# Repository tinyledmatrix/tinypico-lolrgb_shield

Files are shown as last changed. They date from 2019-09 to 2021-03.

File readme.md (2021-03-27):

[Buy a LOL RGB Shield](https://unexpectedmaker.com/shop/tinypico-shield-lolrgb)

## 5*14 RGB-LED shield for tinypico esp-32 board
# General
* for use with tinypico esp32 board
	* https://www.tinypico.com/
	* https://github.com/tinypico 
	* [Buy a TinyPICO](https://unexpectedmaker.com/shop/tinypico-usbc)
	
* Uses 70 WS2812 LEDs in 151 package
* easy to use with fastLED
* @mcauser wrote a  MicroPython library you can find it [here](https://github.com/mcauser/micropython-tinypico-lol-rgb-shield/)
* integrated level-shifter for data signal 3,3V -> 5V
* integrated reset button (optional to use or populate) 
* connection to tinypico: 5V (supply for LEDs), GND, IO4 or IO25, reset (if switch is used)
	* with R1 or R2 user can select to use IO4 or IO25 for the led data line   
# Images 
see also folder /images
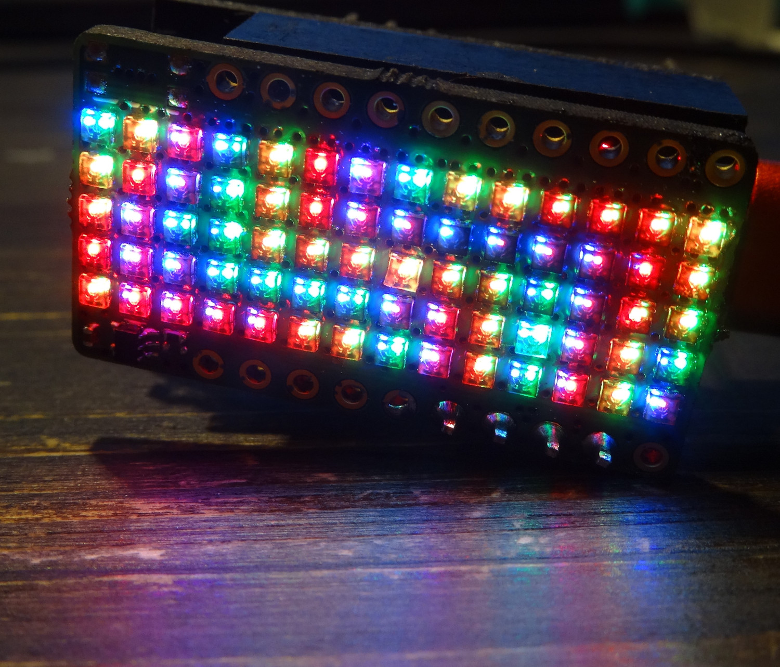
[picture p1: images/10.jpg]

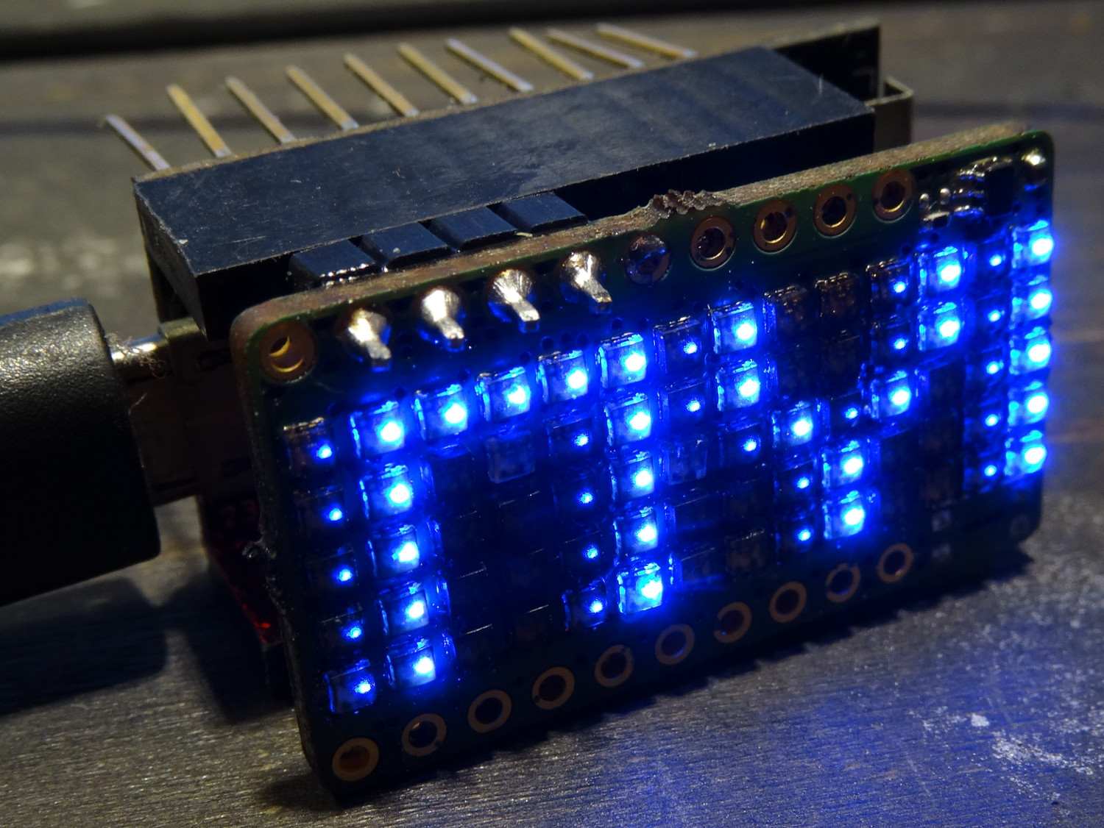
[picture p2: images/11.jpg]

# License 
This is based on the shield template from the orignal repository. So also the licencs is shared.  
These files are released as open source under the CERN license. Please review the license before using these files in your own projects to understand your obligations.

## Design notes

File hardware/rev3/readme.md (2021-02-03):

# Preliminary Files for rev3

Untested! 

Changes:
* Changed Buffer to N-Fet-Buffer 
* Moved datapin to GPIO 14
	* Data-In is no more switchable via resistor 
* Power rail switch to 5V
* rev 3 uses foloowing Pins of tinyPico
	* GND (both are connected - you an use one or both)
	* 3V3 as lower voltage level for level shifter 
	+ 5V as supply voltage for LEDs 
	* GPIO14 data signal for LEDs (needs to be same voltage level as on 3.3V Pin)

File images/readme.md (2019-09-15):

## Some images
Images are in reduced quality. 
If you need more, other or better qualitiy for an articel or similar please contact me. 



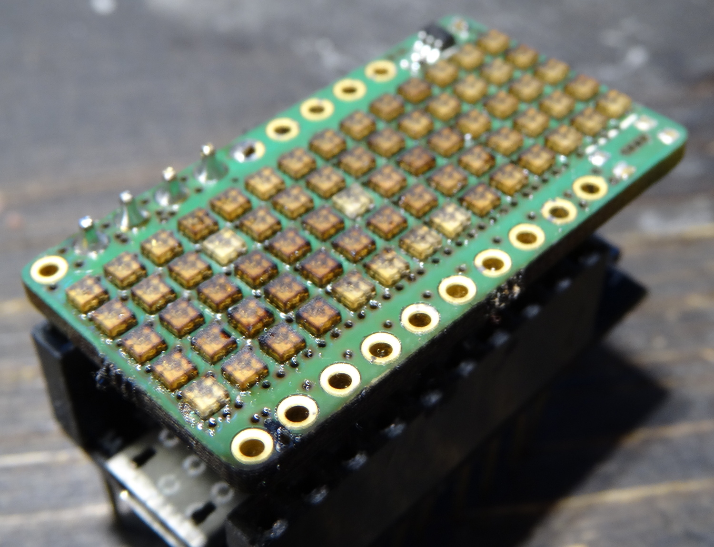
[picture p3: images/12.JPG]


## Licens for all Imges in this folder
CC BY-SA

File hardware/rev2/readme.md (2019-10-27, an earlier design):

# Preliminary Files for rev2

DO NOT USE THIS REVISON. POWERING ALL LEDs FROM THE 3.3V LDO COULD BE PROBLEMATIC!
USE REV3! 

Changes:
* Removed Buffer vor data
* Moved datapin to GPIO 14
	* Data-Oin is nomre switchable via resistor 
* Power rail switch to 3.3V
	* No 5V Power needed anymore
* rev 2 ses foloowing Pins of tinyPico
	* GND (both are connected - youse one or both)
	* 3V3 as supolly voltage for LEDS. (if not used if tinyPico you could also suplly 5V here)
	* GPIO14 data signal for LEDs (neds to be same voltage level as suplly

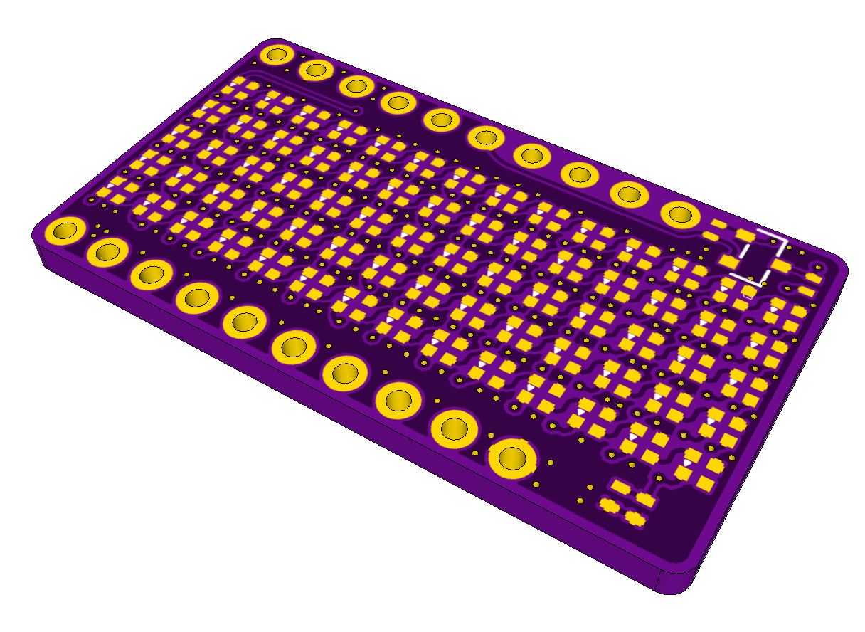
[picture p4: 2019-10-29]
hardware/rev3/renders_PCB/top.JPG

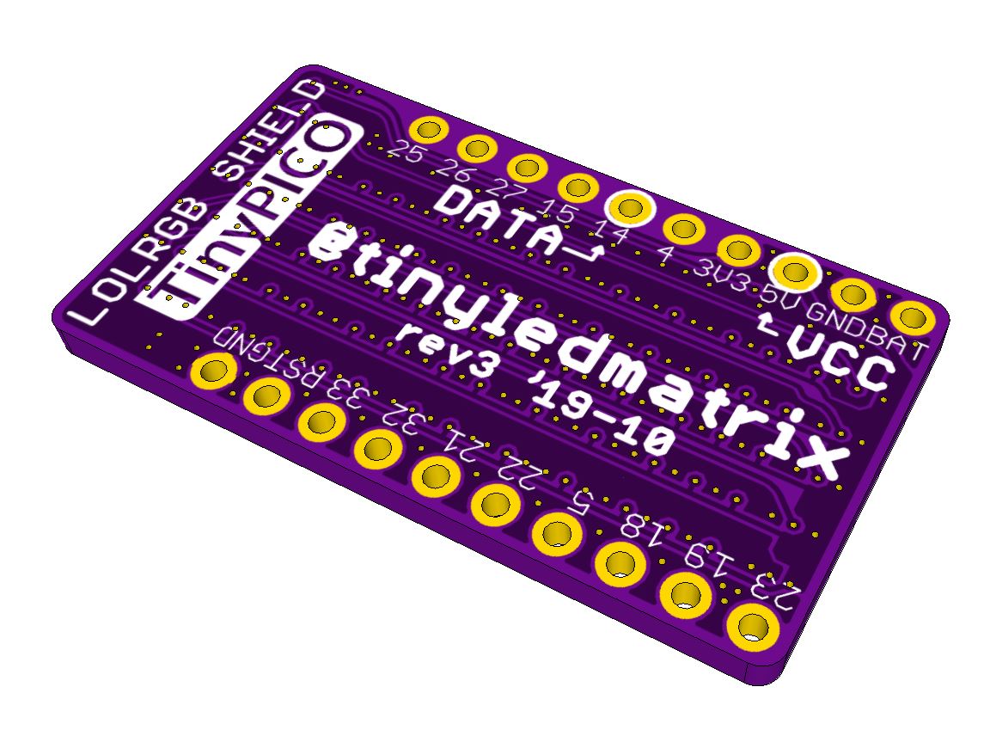
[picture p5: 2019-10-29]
hardware/rev3/renders_PCB/bot.JPG

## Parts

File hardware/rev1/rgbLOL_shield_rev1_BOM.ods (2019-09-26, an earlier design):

Position | Reference | Quantity | Description | Comment | Manufacturer | Package | #Farnell | #Digikey | other sources
1 | LED1-LED70 | 70 | EC15 SK6812 1515 |  | Newstar LED | 1515 (metric) | na | na | Aliexpress, Newstar
2 | R1 | 1 | R0402 0Ohm |  | misc | 0603 | generic | generic
3 | R2 | 1 | R0402 0Ohm | DNP | misc | 0603 | generic | generic
4 | C1 | 1 | C0402 1uF X7R 6.3V |  | misc | 0603 | generic | generic
5 | IC1 | 1 | SN74LV1T34DCKR |  | TI | DCK_R-PDSO-G5 / SC70-5 | 2499915 | 296-37177-1-ND
6 | X1,X2 | 2 | Pinheader 2.54mm 10p | DNP | misc | Pinheader 2.54 | generic | generic

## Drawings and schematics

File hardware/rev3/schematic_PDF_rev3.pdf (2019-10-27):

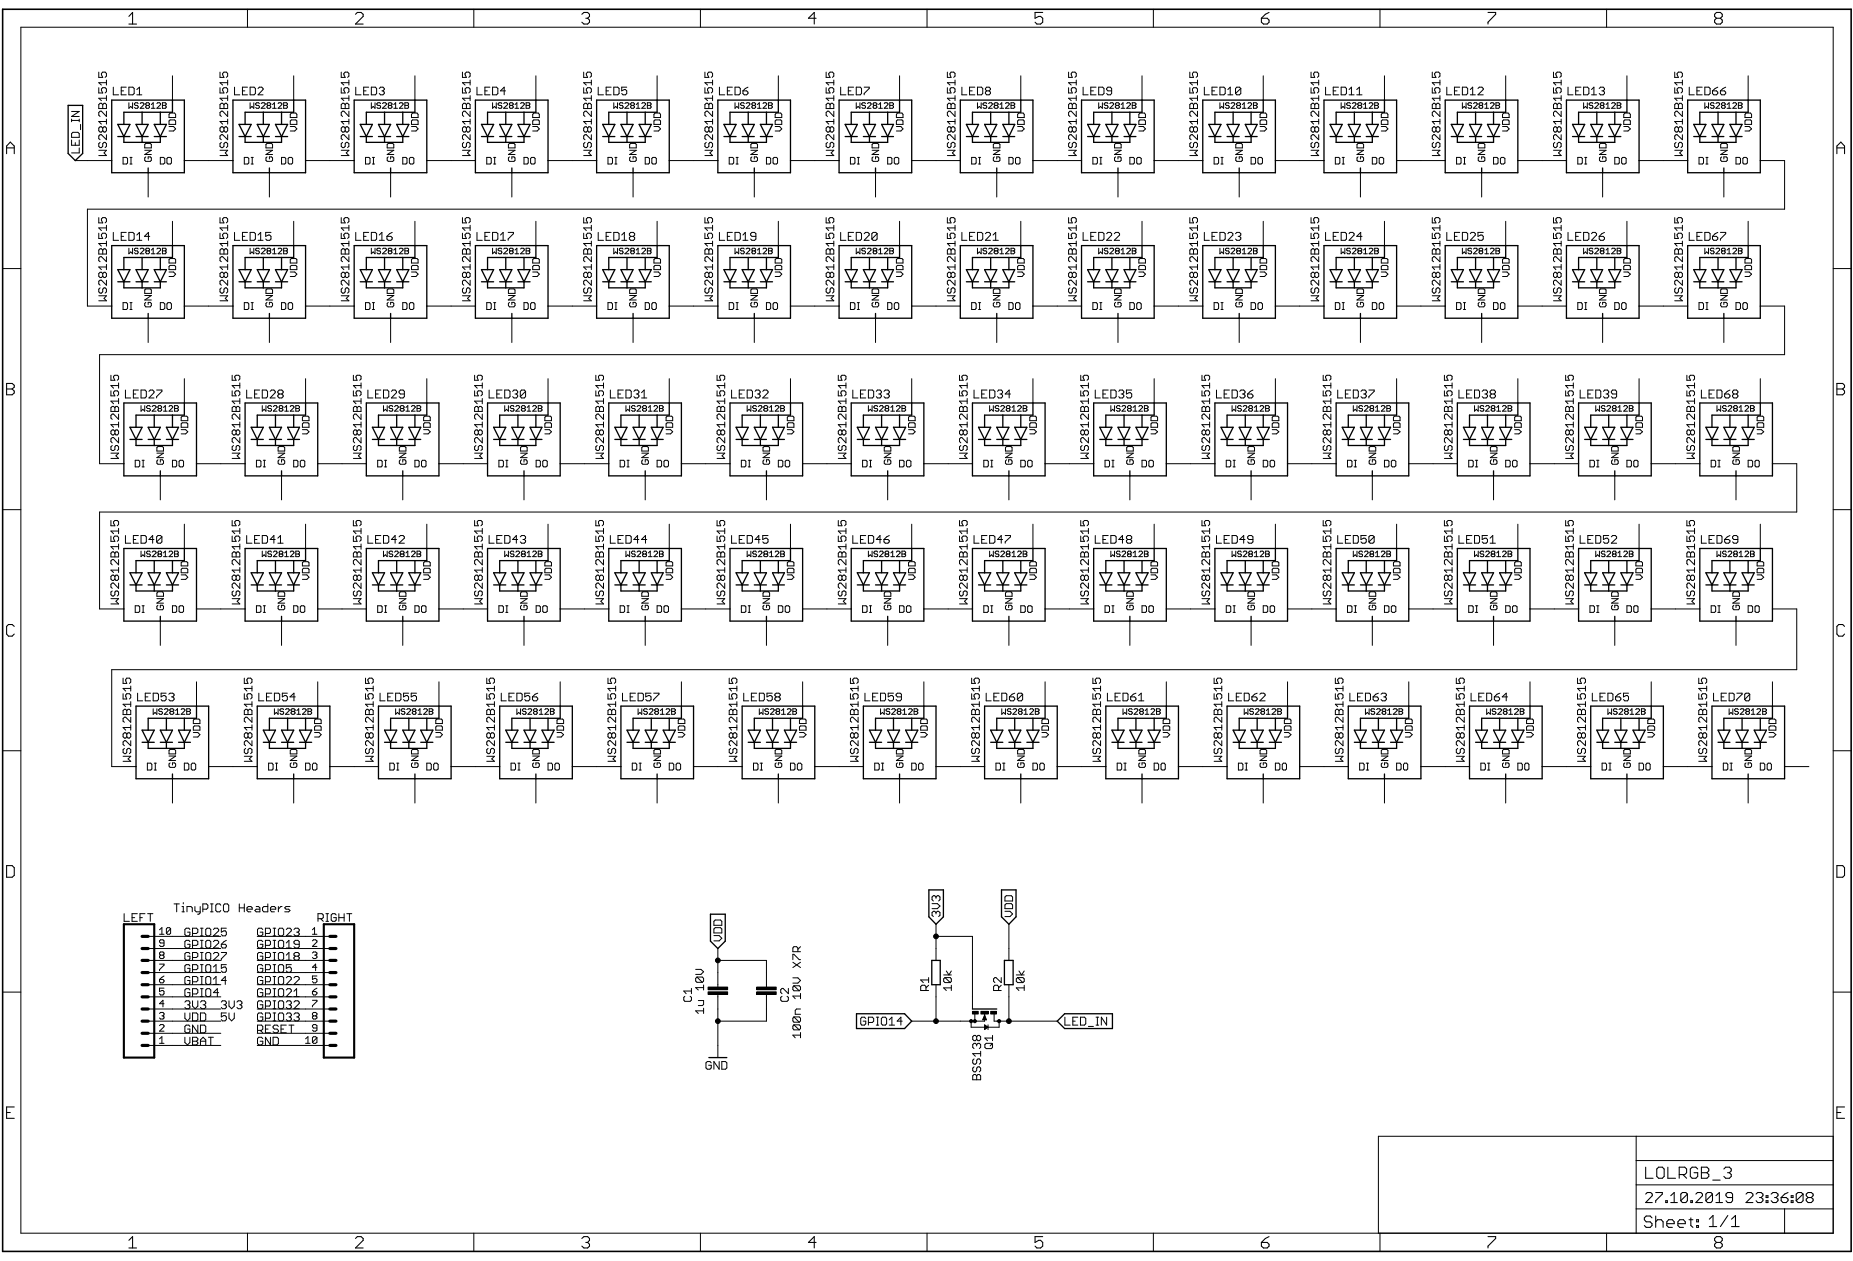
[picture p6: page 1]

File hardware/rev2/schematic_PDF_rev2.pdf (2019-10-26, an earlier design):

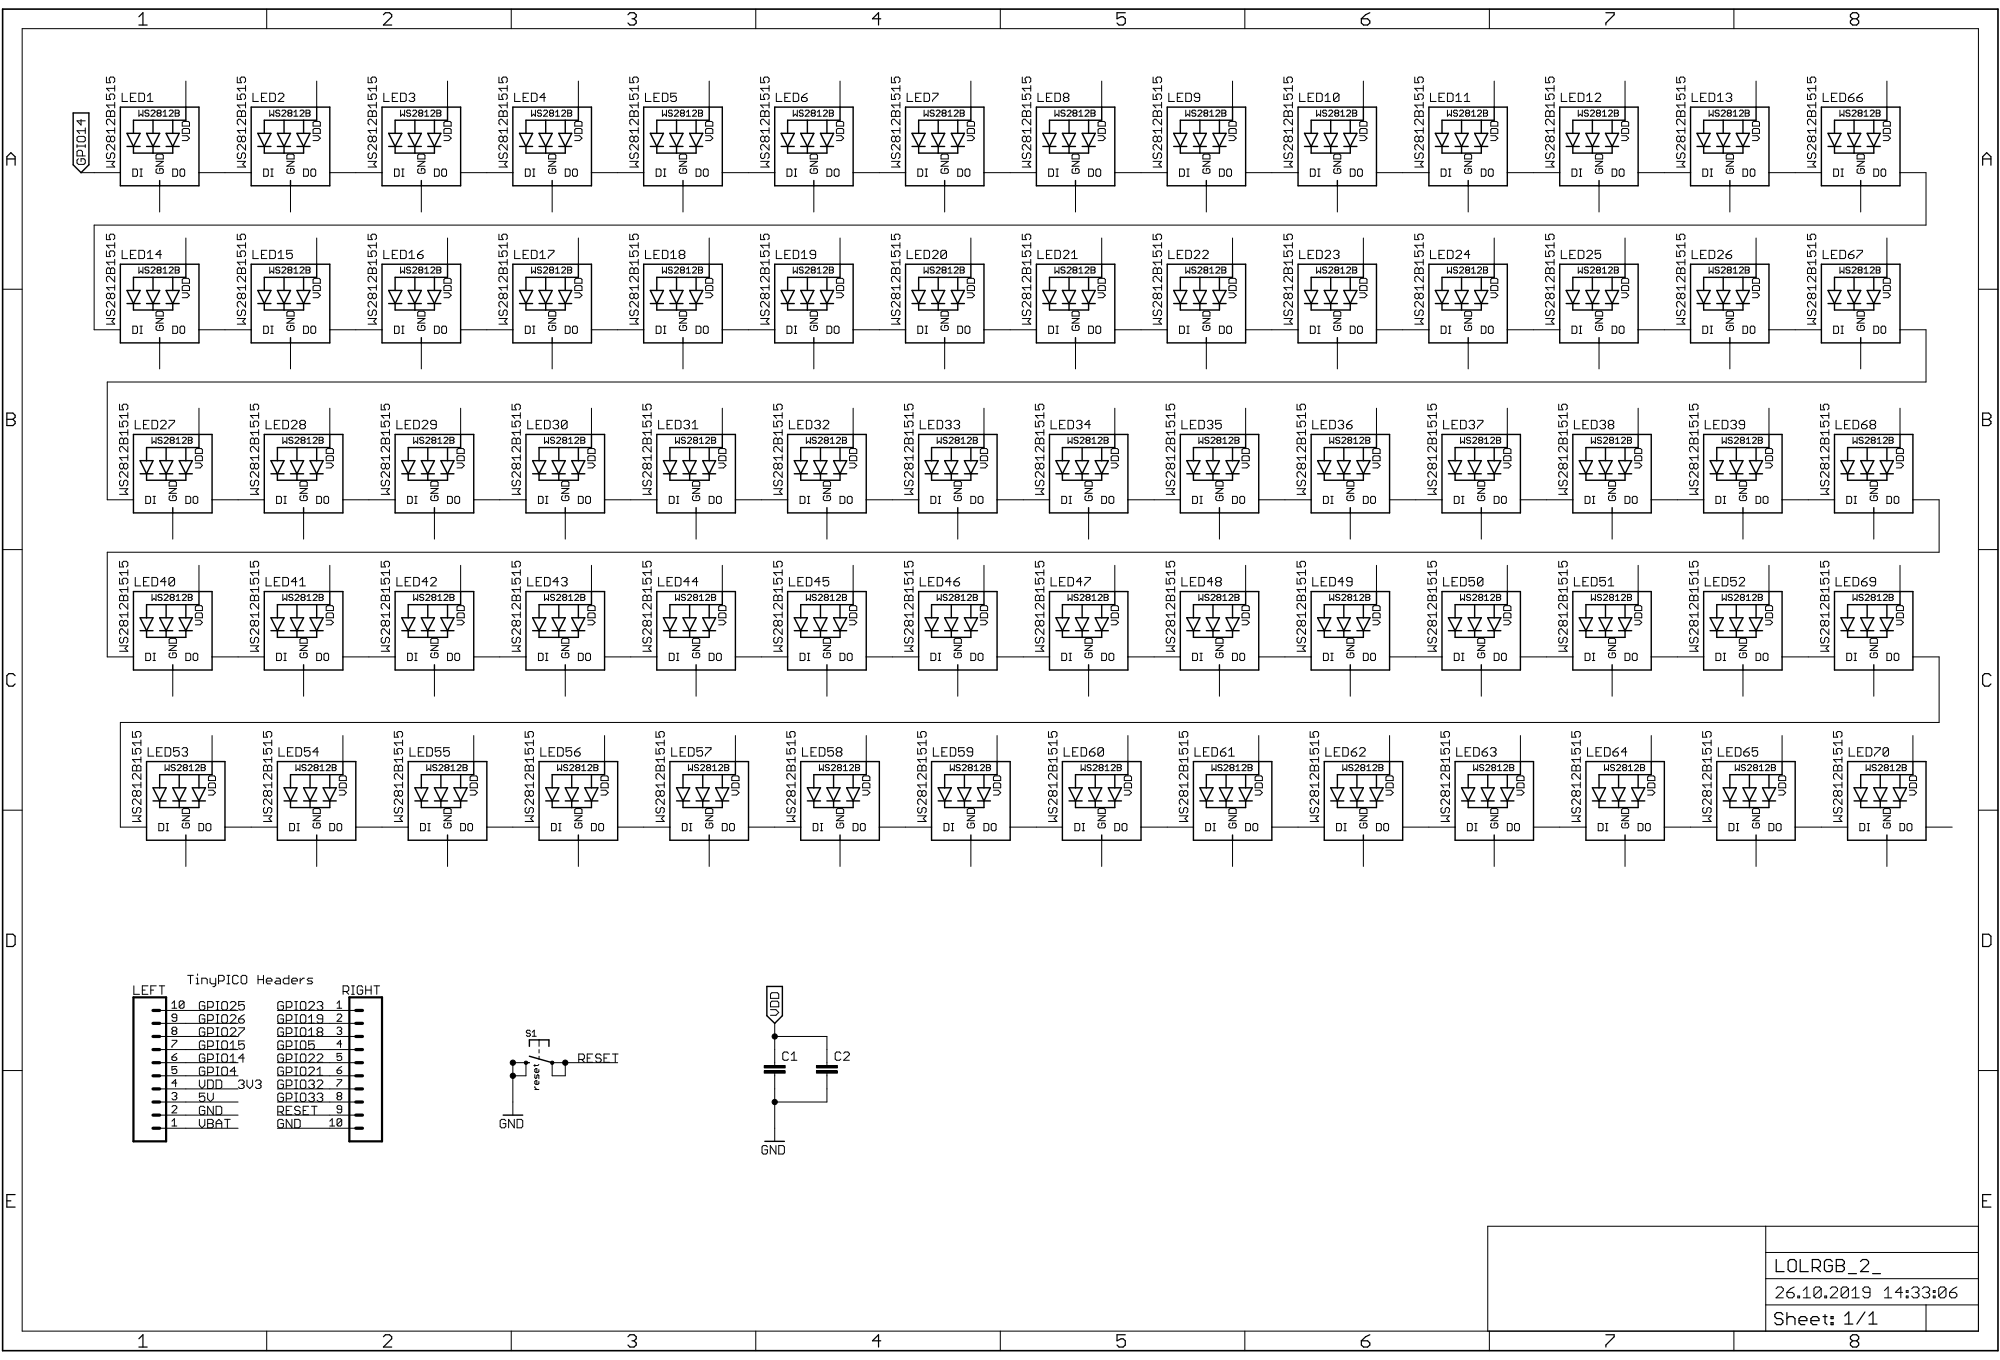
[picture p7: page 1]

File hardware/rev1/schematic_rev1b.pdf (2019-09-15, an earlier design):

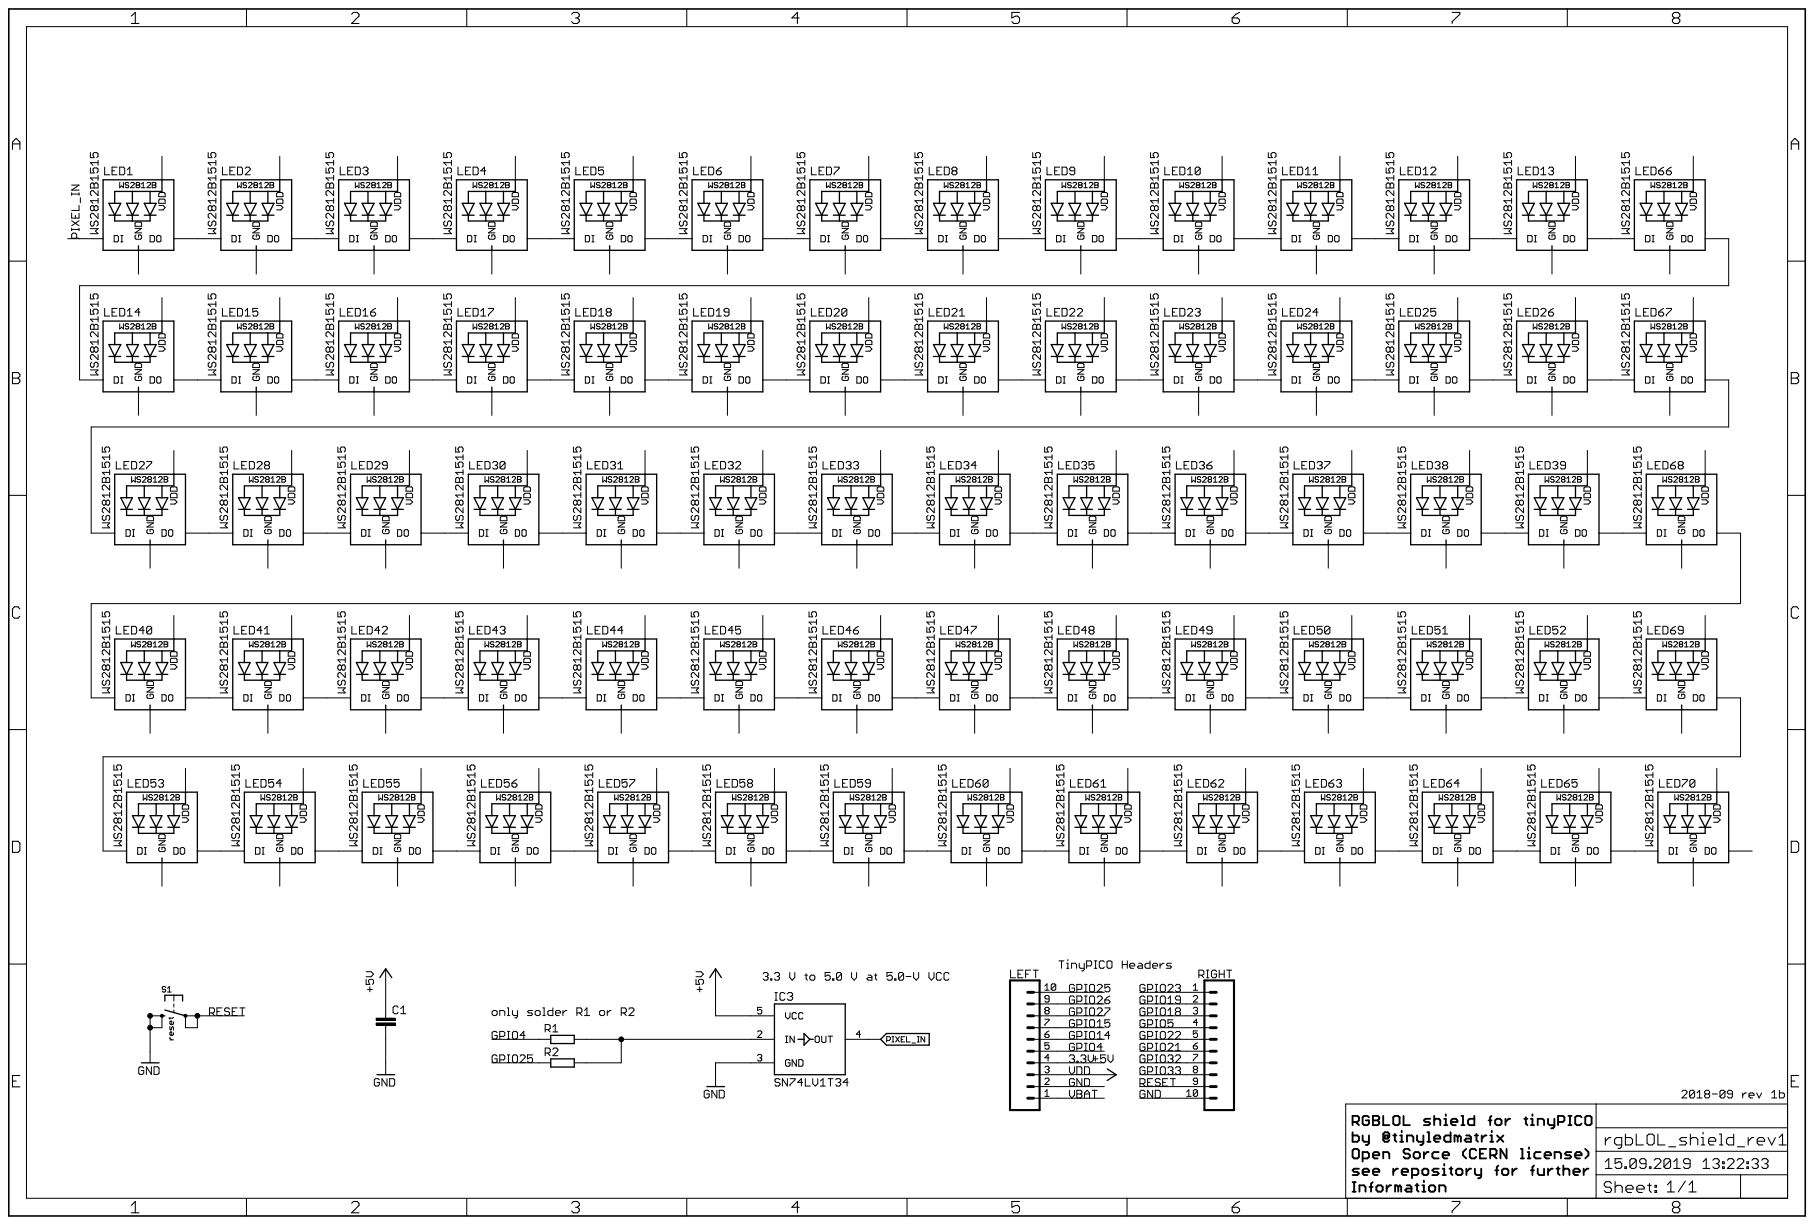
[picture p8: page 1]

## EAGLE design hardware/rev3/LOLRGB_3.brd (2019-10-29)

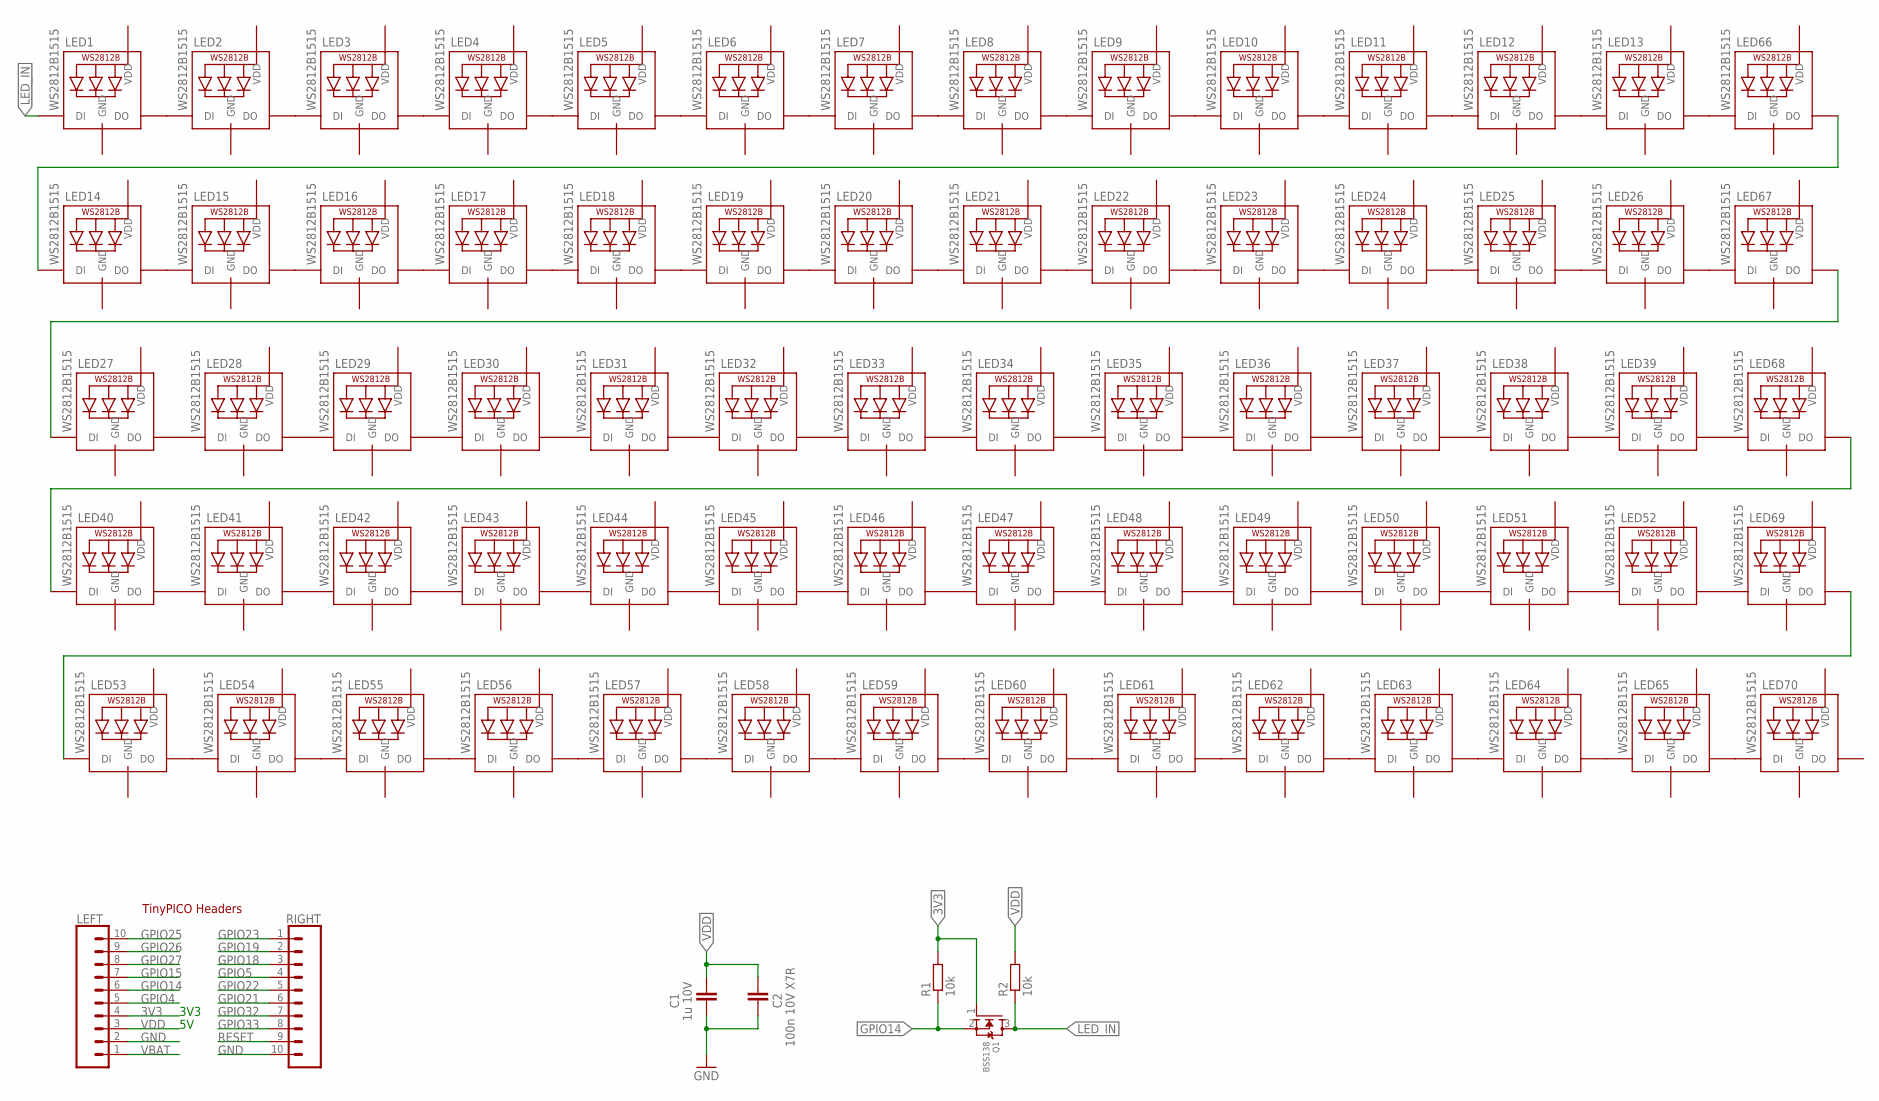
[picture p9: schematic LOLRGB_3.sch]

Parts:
C1: 1u 10V; C0402-VISHAY
C2: 100n 10V X7R; C0402-VISHAY
LED1, LED2, LED3, LED4, LED5, LED6, LED7, LED8, LED9, LED10, LED11, LED12, LED13, LED14, LED15, LED16, LED17, LED18, LED19, LED20, LED21, LED22, LED23, LED24, LED25, LED26, LED27, LED28, LED29, LED30, LED31, LED32, LED33, LED34, LED35, LED36, LED37, LED38, LED39, LED40, LED41, LED42, LED43, LED44, LED45, LED46, LED47, LED48, LED49, LED50, LED51, LED52, LED53, LED54, LED55, LED56, LED57, LED58, LED59, LED60, LED61, LED62, LED63, LED64, LED65, LED66, LED67, LED68, LED69, LED70: WS2812B1515; LED1515
LEFT: TINYPICO_HEADER_10NO_SILK_PTH_FEMALE; 1X10_NO_SILK
Q1: BSS138; SOT23-R
R1, R2: 10k; ADAFRUIT_R0402-VISHAY
RIGHT: TINYPICO_HEADER_10NO_SILK_PTH_FEMALE; 1X10_NO_SILK

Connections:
3V3: LEFT.4, Q1.1 (G), R1.2
GND: C1.2, C2.2, LED1.GND, LED2.GND, LED3.GND, LED4.GND, LED5.GND, LED6.GND, LED7.GND, LED8.GND, LED9.GND, LED10.GND, LED11.GND, LED12.GND, LED13.GND, LED14.GND, LED15.GND, LED16.GND, LED17.GND, LED18.GND, LED19.GND, LED20.GND, LED21.GND, LED22.GND, LED23.GND, LED24.GND, LED25.GND, LED26.GND, LED27.GND, LED28.GND, LED29.GND, LED30.GND, LED31.GND, LED32.GND, LED33.GND, LED34.GND, LED35.GND, LED36.GND, LED37.GND, LED38.GND, LED39.GND, LED40.GND, LED41.GND, LED42.GND, LED43.GND, LED44.GND, LED45.GND, LED46.GND, LED47.GND, LED48.GND, LED49.GND, LED50.GND, LED51.GND, LED52.GND, LED53.GND, LED54.GND, LED55.GND, LED56.GND, LED57.GND, LED58.GND, LED59.GND, LED60.GND, LED61.GND, LED62.GND, LED63.GND, LED64.GND, LED65.GND, LED66.GND, LED67.GND, LED68.GND, LED69.GND, LED70.GND, LEFT.2, RIGHT.10
GPIO4: LEFT.5
GPIO5: RIGHT.4
GPIO14: LEFT.6, Q1.2 (S), R1.1
GPIO15: LEFT.7
GPIO18: RIGHT.3
GPIO19: RIGHT.2
GPIO21: RIGHT.6
GPIO22: RIGHT.5
GPIO23: RIGHT.1
GPIO25: LEFT.10
GPIO26: LEFT.9
GPIO27: LEFT.8
GPIO32: RIGHT.7
GPIO33: RIGHT.8
LED_IN: LED1.DIN (DI), Q1.3 (D), R2.1
unnamed: LED13.DOUT (DO), LED66.DIN (DI)
unnamed: LED1.DOUT (DO), LED2.DIN (DI)
unnamed: LED2.DOUT (DO), LED3.DIN (DI)
unnamed: LED3.DOUT (DO), LED4.DIN (DI)
unnamed: LED4.DOUT (DO), LED5.DIN (DI)
unnamed: LED5.DOUT (DO), LED6.DIN (DI)
unnamed: LED6.DOUT (DO), LED7.DIN (DI)
unnamed: LED7.DOUT (DO), LED8.DIN (DI)
unnamed: LED8.DOUT (DO), LED9.DIN (DI)
unnamed: LED10.DOUT (DO), LED11.DIN (DI)
unnamed: LED9.DOUT (DO), LED10.DIN (DI)
unnamed: LED11.DOUT (DO), LED12.DIN (DI)
unnamed: LED12.DOUT (DO), LED13.DIN (DI)
unnamed: LED14.DOUT (DO), LED15.DIN (DI)
unnamed: LED15.DOUT (DO), LED16.DIN (DI)
unnamed: LED16.DOUT (DO), LED17.DIN (DI)
unnamed: LED17.DOUT (DO), LED18.DIN (DI)
unnamed: LED18.DOUT (DO), LED19.DIN (DI)
unnamed: LED19.DOUT (DO), LED20.DIN (DI)
unnamed: LED20.DOUT (DO), LED21.DIN (DI)
unnamed: LED21.DOUT (DO), LED22.DIN (DI)
unnamed: LED23.DOUT (DO), LED24.DIN (DI)
unnamed: LED22.DOUT (DO), LED23.DIN (DI)
unnamed: LED24.DOUT (DO), LED25.DIN (DI)
unnamed: LED25.DOUT (DO), LED26.DIN (DI)
unnamed: LED27.DOUT (DO), LED28.DIN (DI)
unnamed: LED28.DOUT (DO), LED29.DIN (DI)
unnamed: LED29.DOUT (DO), LED30.DIN (DI)
unnamed: LED30.DOUT (DO), LED31.DIN (DI)
unnamed: LED31.DOUT (DO), LED32.DIN (DI)
unnamed: LED32.DOUT (DO), LED33.DIN (DI)
unnamed: LED33.DOUT (DO), LED34.DIN (DI)
unnamed: LED34.DOUT (DO), LED35.DIN (DI)
unnamed: LED36.DOUT (DO), LED37.DIN (DI)
unnamed: LED35.DOUT (DO), LED36.DIN (DI)
unnamed: LED37.DOUT (DO), LED38.DIN (DI)
unnamed: LED38.DOUT (DO), LED39.DIN (DI)
unnamed: LED40.DOUT (DO), LED41.DIN (DI)
unnamed: LED41.DOUT (DO), LED42.DIN (DI)
unnamed: LED42.DOUT (DO), LED43.DIN (DI)
unnamed: LED43.DOUT (DO), LED44.DIN (DI)
unnamed: LED44.DOUT (DO), LED45.DIN (DI)
unnamed: LED45.DOUT (DO), LED46.DIN (DI)
unnamed: LED46.DOUT (DO), LED47.DIN (DI)
unnamed: LED47.DOUT (DO), LED48.DIN (DI)
unnamed: LED49.DOUT (DO), LED50.DIN (DI)
unnamed: LED48.DOUT (DO), LED49.DIN (DI)
unnamed: LED50.DOUT (DO), LED51.DIN (DI)
unnamed: LED51.DOUT (DO), LED52.DIN (DI)
unnamed: LED53.DOUT (DO), LED54.DIN (DI)
unnamed: LED54.DOUT (DO), LED55.DIN (DI)
unnamed: LED55.DOUT (DO), LED56.DIN (DI)
unnamed: LED56.DOUT (DO), LED57.DIN (DI)
unnamed: LED57.DOUT (DO), LED58.DIN (DI)
unnamed: LED58.DOUT (DO), LED59.DIN (DI)
unnamed: LED59.DOUT (DO), LED60.DIN (DI)
unnamed: LED60.DOUT (DO), LED61.DIN (DI)
unnamed: LED62.DOUT (DO), LED63.DIN (DI)
unnamed: LED61.DOUT (DO), LED62.DIN (DI)
unnamed: LED63.DOUT (DO), LED64.DIN (DI)
unnamed: LED64.DOUT (DO), LED65.DIN (DI)
unnamed: LED14.DIN (DI), LED66.DOUT (DO)
unnamed: LED26.DOUT (DO), LED67.DIN (DI)
unnamed: LED39.DOUT (DO), LED68.DIN (DI)
unnamed: LED52.DOUT (DO), LED69.DIN (DI)
unnamed: LED65.DOUT (DO), LED70.DIN (DI)
unnamed: LED27.DIN (DI), LED67.DOUT (DO)
unnamed: LED40.DIN (DI), LED68.DOUT (DO)
unnamed: LED53.DIN (DI), LED69.DOUT (DO)
RESET: RIGHT.9
VBAT: LEFT.1
VDD: C1.1, C2.1, LED1.VDD, LED2.VDD, LED3.VDD, LED4.VDD, LED5.VDD, LED6.VDD, LED7.VDD, LED8.VDD, LED9.VDD, LED10.VDD, LED11.VDD, LED12.VDD, LED13.VDD, LED14.VDD, LED15.VDD, LED16.VDD, LED17.VDD, LED18.VDD, LED19.VDD, LED20.VDD, LED21.VDD, LED22.VDD, LED23.VDD, LED24.VDD, LED25.VDD, LED26.VDD, LED27.VDD, LED28.VDD, LED29.VDD, LED30.VDD, LED31.VDD, LED32.VDD, LED33.VDD, LED34.VDD, LED35.VDD, LED36.VDD, LED37.VDD, LED38.VDD, LED39.VDD, LED40.VDD, LED41.VDD, LED42.VDD, LED43.VDD, LED44.VDD, LED45.VDD, LED46.VDD, LED47.VDD, LED48.VDD, LED49.VDD, LED50.VDD, LED51.VDD, LED52.VDD, LED53.VDD, LED54.VDD, LED55.VDD, LED56.VDD, LED57.VDD, LED58.VDD, LED59.VDD, LED60.VDD, LED61.VDD, LED62.VDD, LED63.VDD, LED64.VDD, LED65.VDD, LED66.VDD, LED67.VDD, LED68.VDD, LED69.VDD, LED70.VDD, LEFT.3, R2.2

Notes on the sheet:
TinyPICO Headers
3V3

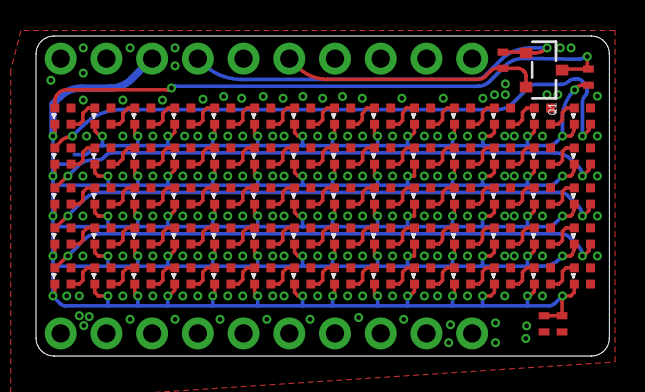
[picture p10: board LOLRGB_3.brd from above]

Board: 2 copper layers, 31.9 x 17.8 mm, 77 parts (0 on the bottom side), 74 nets.

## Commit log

2019-09-15 added hw-files
    [rgbLOL_shield_rev1.brd, rgbLOL_shield_rev1.sch]
2019-09-26 BOM.sheet with order Informations created
    [rgbLOL_shield_rev1_BOM.ods]
2019-10-26 added HW rev2
    Files for second rev. See rev2 readme/changelog for more details
    [LOLRGB_2.brd, LOLRGB_2.sch]
2019-10-27 added rev3
    [LOLRGB_3.brd, LOLRGB_3.sch]
2019-10-29 SOT23-Footprint changed
    [LOLRGB_3.brd, LOLRGB_3.sch]

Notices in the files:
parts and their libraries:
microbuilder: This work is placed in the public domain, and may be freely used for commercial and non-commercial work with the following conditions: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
